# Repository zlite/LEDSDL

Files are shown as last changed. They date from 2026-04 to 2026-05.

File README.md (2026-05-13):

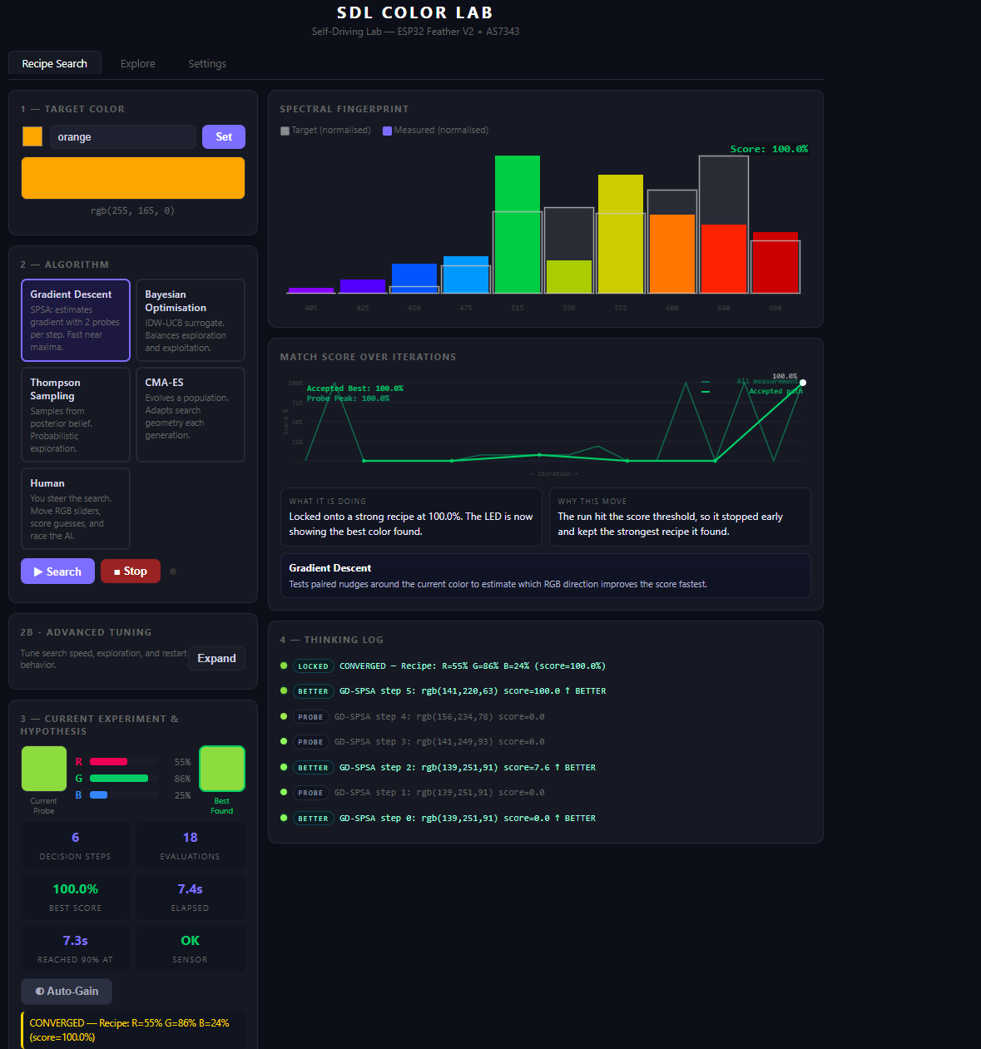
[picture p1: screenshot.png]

This is a minimal self-driving lab demonstration to "discover" color theory by doing an exploration/exploitation search of color space through driving a RGB LED and measuring it with a 14-channel color sensor. Users (often students) will learn about different SDL algorithms, such as Baysean Optimization and Gradient Descent, understanding why some are better at the task than others, and be able to try to beat the AI with "Human" mode. It all works via a web UI, but involves real-world data, where you can watch the experiments running in real time.

The whole thing can be made for $40, with no soldering required. It has an optional 400mah LiPo battery that the Feather can automatically recharge, making this a totally self-contained and portable SDL.

Instructions: Load code onto ESP32 with the Platormio extension in VSCode (change the port in the ini file to whatever your ESP32 shows up as). Codex or Claude Code extensions in VS Code will do this for you. Alternatively, you can just load the file on the ESP32 using the Arduino IDE.

3D print the two parts: [base](base.stl) and [cover](cover.stl). Everything is snap-together, no screws required.

If you haven't set your wifi details in the code, on startup after 30 seconds it will create its own Wifi access point called "SDL". Connect your phone or laptop to it and when prompted to login via a brower it will automatically take you to the app. Once in the app, in the setting tab you can search for your local Wifi network and enter in your password (if any) and press "Connect" (you only need to do this once; it will remember it next time). Once it's connected to your network, you should be able to open the UI in your web browser by just typing "sdl.local" in the URL bar. 

When plugged in via USB, the Feather will automatically charge the Lipo if you're using one.

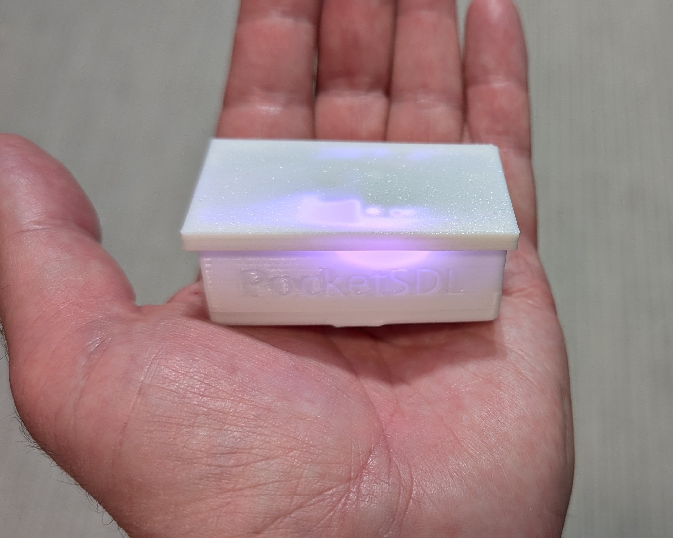
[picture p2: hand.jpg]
outside


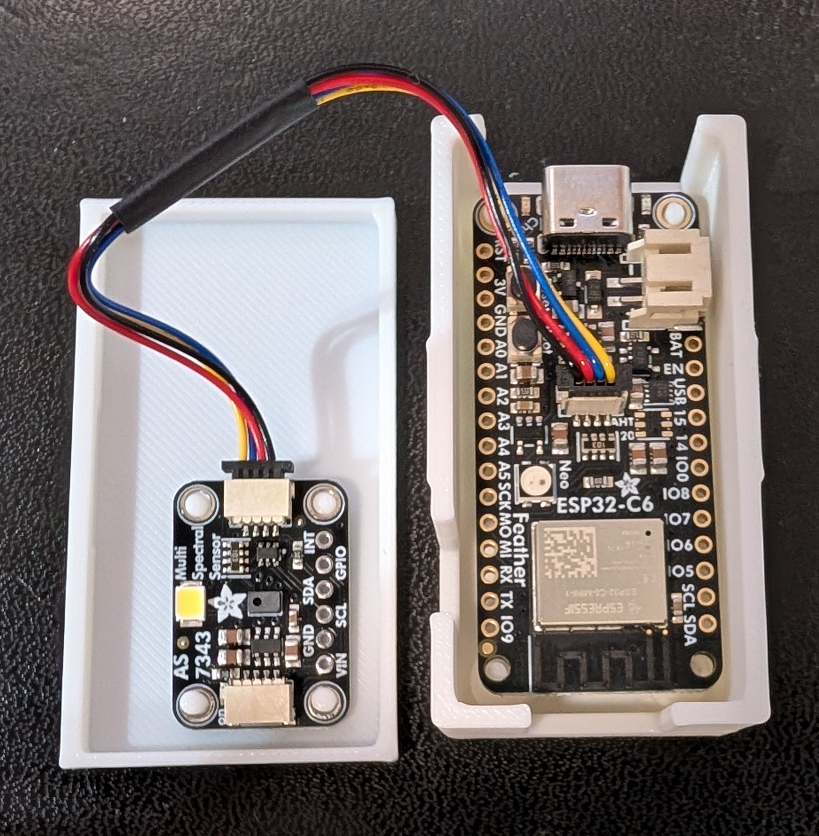
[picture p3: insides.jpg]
insides

----
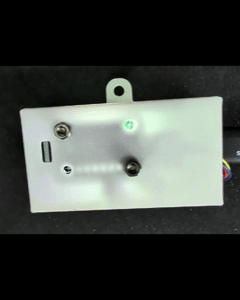
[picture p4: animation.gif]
flashing


**BOM**:
- [Adafruit Feather ESP32 C6](https://www.adafruit.com/product/5933) ($14.95)
- [Adafruit 10-channel color sensor](https://www.adafruit.com/product/4698) ($18.95)
- [Adafruit Stemma 4-pin cable, 50mm](https://www.adafruit.com/product/4399)  ($0.95, if out of stock, a longer cable can work, too)
- Optional [Adafruit 400mAh battery with short cable](https://www.adafruit.com/product/3898) ($6.95)

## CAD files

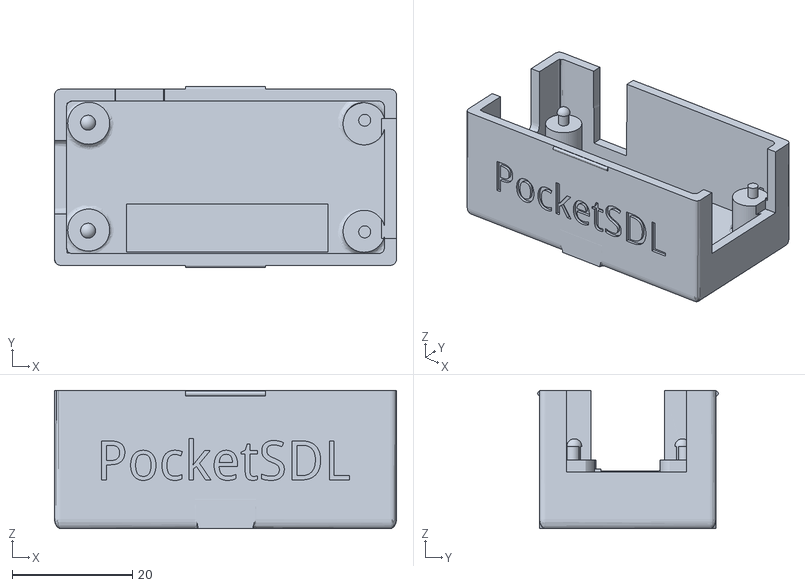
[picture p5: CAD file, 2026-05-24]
base.stl
57.0 x 30.1 x 23.0

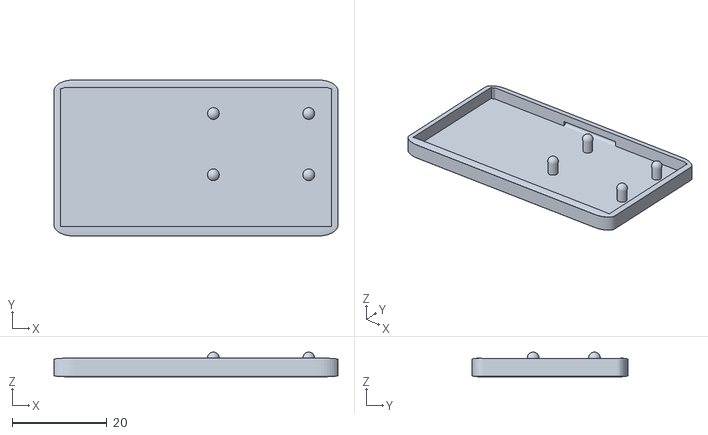
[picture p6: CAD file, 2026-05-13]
cover.stl
60.0 x 33.0 x 5.25

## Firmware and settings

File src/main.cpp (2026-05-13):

#include <Arduino.h>
#include <WiFi.h>
#include <DNSServer.h>
#include <AsyncTCP.h>
#include <ESPAsyncWebServer.h>
#include <ESPmDNS.h>
#include <Wire.h>
#include <math.h>
#include <Preferences.h>
#include <Adafruit_NeoPixel.h>

#if defined(SDL_SENSOR_AS7341) && defined(SDL_SENSOR_AS7343)
#error "Define only one of SDL_SENSOR_AS7341 or SDL_SENSOR_AS7343."
#endif

#if !defined(SDL_SENSOR_AS7341) && !defined(SDL_SENSOR_AS7343)
#define SDL_SENSOR_AS7343 1
#endif

#if defined(SDL_SENSOR_AS7341)
#include <Adafruit_AS7341.h>
#else
#include <Adafruit_AS7343.h>
#endif

// ── Hardware ──────────────────────────────────────────────────────────────────
#ifndef PIN_NEOPIXEL
#define PIN_NEOPIXEL 0
#endif

#if defined(PIN_NEOPIXEL_I2C_POWER)
#define SDL_NEOPIXEL_POWER PIN_NEOPIXEL_I2C_POWER
#elif defined(NEOPIXEL_I2C_POWER)
#define SDL_NEOPIXEL_POWER NEOPIXEL_I2C_POWER
#else
#define SDL_NEOPIXEL_POWER 2
#endif

#define NEOPIXEL_PIN   PIN_NEOPIXEL
#define NEOPIXEL_POWER SDL_NEOPIXEL_POWER
#define LED_BRIGHTNESS 200

#ifndef WIFI_SSID
#define WIFI_SSID "YOUR_WIFI_SSID"
#endif

#ifndef WIFI_PASS
#define WIFI_PASS "YOUR_WIFI_PASSWORD"
#endif

static const char WIFI_SSID_VALUE[] = WIFI_SSID;
static const char WIFI_PASS_VALUE[] = WIFI_PASS;
static const char AP_FALLBACK_SSID[] = "SDL";

#if defined(SDL_SENSOR_AS7341)
using SpectralSensor = Adafruit_AS7341;
using SensorGain = as7341_gain_t;
static const char SENSOR_DISPLAY_NAME[] = "AS7341";
static const char SENSOR_SUBTITLE[] = "Self-Driving Lab &mdash; ESP32 Feather V2 + AS7341";
static const int NUM_CH = 10;
static const int RAW_READ_CH = 12;
static const int N_SPEC = 8;
static const int SPEC_CH[] = {0,1,2,3,6,7,8,9};
static const float SPEC_WL[] = {415,445,480,515,555,590,630,680};
static const float W_R[NUM_CH]={0.00f,0.02f,0.08f,0.28f,0.00f,0.00f,0.55f,0.82f,1.00f,0.46f};
static const float W_G[NUM_CH]={0.03f,0.16f,0.55f,0.95f,0.00f,0.00f,0.78f,0.28f,0.03f,0.00f};
static const float W_B[NUM_CH]={0.52f,0.95f,0.78f,0.18f,0.00f,0.00f,0.01f,0.00f,0.00f,0.00f};
static const char SENSOR_JS_SPEC_IDX[] = "[0,1,2,3,6,7,8,9]";
static const char SENSOR_JS_SPEC_WL[] = "[415,445,480,515,555,590,630,680]";
static const char SENSOR_JS_SPEC_COL[] = "['#7f00ff','#2d5bff','#00a6ff','#00c96a','#c7d400','#ff9b00','#ff4d2b','#cc0017']";
static const char SENSOR_JS_CH_COL[] = "['#7f00ff','#2d5bff','#00a6ff','#00c96a','#bfbfbf','#777','#c7d400','#ff9b00','#ff4d2b','#cc0017']";
static const char SENSOR_JS_CH_LBL[] = "['415','445','480','515','Clr','NIR','555','590','630','680']";
static const char SENSOR_JS_W_R[] = "[0,0.02,0.08,0.28,0,0,0.55,0.82,1,0.46]";
static const char SENSOR_JS_W_G[] = "[0.03,0.16,0.55,0.95,0,0,0.78,0.28,0.03,0]";
static const char SENSOR_JS_W_B[] = "[0.52,0.95,0.78,0.18,0,0,0.01,0,0,0]";
static const char SENSOR_LOG_HEADER_HTML[] = "<th>415</th><th>445</th><th>480</th><th>515</th><th>555</th><th>590</th><th>630</th><th>680</th><th>Clr</th><th>NIR</th>";
static const char SENSOR_JS_LOG_IDX[] = "[0,1,2,3,6,7,8,9,4,5]";
#else
using SpectralSensor = Adafruit_AS7343;
using SensorGain = as7343_gain_t;
static const char SENSOR_DISPLAY_NAME[] = "AS7343";
static const char SENSOR_SUBTITLE[] = "Self-Driving Lab &mdash; ESP32 Feather V2 + AS7343";
static const int NUM_CH = 18;
static const int RAW_READ_CH = 18;
static const int N_SPEC = 10;
static const int SPEC_CH[] = {12,6,0,7,8,15,1,2,9,13};
static const float SPEC_WL[] = {405,425,450,475,515,550,555,600,640,690};
static const float W_R[NUM_CH]={0.00f,0.11f,0.68f,0.00f,0,0,0.00f,0.00f,0.00f,1.00f,0,0,0.00f,0.39f,0.02f,0.10f,0,0};
static const float W_G[NUM_CH]={0.08f,0.74f,0.12f,0.00f,0,0,0.01f,0.32f,0.93f,0.01f,0,0,0.00f,0.00f,0.00f,0.82f,0,0};
static const float W_B[NUM_CH]={0.98f,0.01f,0.00f,0.00f,0,0,0.49f,0.73f,0.06f,0.00f,0,0,0.14f,0.00f,0.00f,0.01f,0,0};
static const char SENSOR_JS_SPEC_IDX[] = "[12,6,0,7,8,15,1,2,9,13]";
static const char SENSOR_JS_SPEC_WL[] = "[405,425,450,475,515,550,555,600,640,690]";
static const char SENSOR_JS_SPEC_COL[] = "['#8800ff','#5500ff','#0055ff','#0099ff','#00cc44','#aacc00','#cccc00','#ff7700','#ff2200','#cc0000']";
static const char SENSOR_JS_CH_COL[] = "['#6600CC','#99CC00','#FF7700','#888','#bbb','#999','#4400FF','#0044FF','#00BB00','#FF2200','#bbb','#999','#9900FF','#CC0000','#880000','#CCEE00','#bbb','#999']";
static const char SENSOR_JS_CH_LBL[] = "['450','555','600','NIR','Cl','Cl','425','475','515','640','Cl','Cl','405','690','745','550','Cl','Cl']";
static const char SENSOR_JS_W_R[] = "[0,0.11,0.68,0,0,0,0,0,0,1,0,0,0,0.39,0.02,0.10,0,0]";
static const char SENSOR_JS_W_G[] = "[0.08,0.74,0.12,0,0,0,0.01,0.32,0.93,0.01,0,0,0,0,0,0.82,0,0]";
static const char SENSOR_JS_W_B[] = "[0.98,0.01,0,0,0,0,0.49,0.73,0.06,0,0,0,0.14,0,0,0.01,0,0]";
static const char SENSOR_LOG_HEADER_HTML[] = "<th>405</th><th>425</th><th>450</th><th>475</th><th>515</th><th>550</th><th>600</th><th>640</th><th>690</th><th>Clr</th>";
static const char SENSOR_JS_LOG_IDX[] = "[12,6,0,7,8,15,2,9,13,4]";
#endif

Adafruit_NeoPixel pixel(1, NEOPIXEL_PIN, NEO_GRB + NEO_KHZ800);
SpectralSensor    spectralSensor;
AsyncWebServer    server(80);
Preferences       prefs;
DNSServer         dnsServer;

static uint8_t ledR=0, ledG=0, ledB=0;
static bool    sensorOK=false;
static bool    apFallbackActive=false;
static String  wifiSSID;
static String  wifiPass;
static String  deviceHostName = "sdl";
static String  apSSID = AP_FALLBACK_SSID;

void setLED(uint8_t r, uint8_t g, uint8_t b){
  ledR=r; ledG=g; ledB=b;
  pixel.setPixelColor(0, pixel.Color(r,g,b)); pixel.show();
}

// ── Channel layout (18-ch mode) ───────────────────────────────────────────────
//  0:FZ/450  1:FY/555  2:FXL/600  3:NIR/855  4,5:CLR0
//  6:F2/425  7:F3/475  8:F4/515   9:F6/640   10,11:CLR1
// 12:F1/405 13:F7/690 14:F8/745  15:F5/550   16,17:CLR2
// ── Buffers ───────────────────────────────────────────────────────────────────
struct Reading { uint8_t r,g,b; uint16_t ch[NUM_CH]; };
static const int LOG_MAX=120; static Reading logBuf[LOG_MAX];
static int logHead=0, logCount=0;

struct Thought { uint8_t r,g,b; float score; bool improved; char msg[96]; };
static const int TH_MAX=50; static Thought thBuf[TH_MAX];
static int thHead=0, thCount=0;

static const int SCORE_MAX=200; static float scoreHist[SCORE_MAX];
static float acceptedScoreHist[SCORE_MAX];
static int scoreHead=0, scoreLen=0;
static int sensorReadFailures=0;

static String jsonEscape(const char* src);
static void setStateMessage(const char* msg);
static void stopExperiment(const char* msg, bool turnLedOff);
static bool hasCompileTimeWiFiCreds();
static bool loadStoredWiFiCreds();
static bool saveStoredWiFiCreds(const String& ssid, const String& pass);
static void loadNetworkSettings();
static bool saveNetworkSettings(const String& host, const String& ap);
static String normalizeHostName(String host);
static String normalizeApSsid(String ssid);
static String readSerialLine(bool echoInput = true);
static bool promptForWiFiCreds();
static void connectWiFi();
static void startFallbackAp();
static void startMdns();
static bool connectToNetwork(const String& ssid, const String& pass, uint32_t timeoutMs);
static void handleCaptivePortal(AsyncWebServerRequest* request);
static bool beginSpectralSensor();
static bool readSpectralChannels(uint16_t* readings);
static bool setSpectralGainIndex(int gainIdx);
static String buildHtml();
static bool parseJsonFloat(const String& body, const char* key, float& valueOut);
static String buildStatusJson();
static String buildScoresJson();
static String buildThoughtsJson();
static String buildLogJson();
static String buildSnapshotJson(bool includeLog);
static void queueHumanProbe(uint8_t r, uint8_t g, uint8_t b);
static String buildSettingsJson();
static void handleSettingsGet(AsyncWebServerRequest* request);
static void handleSettingsPost(AsyncWebServerRequest* request);
static void handleWifiScan(AsyncWebServerRequest* request);
static void handleWifiConnect(AsyncWebServerRequest* request);
static bool getRequestInt(AsyncWebServerRequest* request, const char* key, int& valueOut);
static bool getRequestFloat(AsyncWebServerRequest* request, const char* key, float& valueOut);
static bool getRequestString(AsyncWebServerRequest* request, const char* key, String& valueOut);
static bool getRequestRgb(AsyncWebServerRequest* request, uint8_t& r, uint8_t& g, uint8_t& b);

void pushScore(float s){
  int idx=scoreHead%SCORE_MAX;
  scoreHist[idx]=s;
  acceptedScoreHist[idx]=-1.0f;
  scoreHead++;
  if(scoreLen<SCORE_MAX)scoreLen++;
}
void pushAcceptedScore(float s){
  int idx=(scoreHead-1+SCORE_MAX)%SCORE_MAX;
  acceptedScoreHist[idx]=s;
}

void addThought(uint8_t r,uint8_t g,uint8_t b,float sc,bool imp,const char* msg){
  Thought& t=thBuf[thHead%TH_MAX]; t.r=r;t.g=g;t.b=b;t.score=sc;t.improved=imp;
  strncpy(t.msg,msg,95); t.msg[95]='\0'; thHead++; if(thCount<TH_MAX)thCount++;
  Serial.printf("[SDL] %s\n",msg);
}

// ── Spectral helpers ──────────────────────────────────────────────────────────
static float recTgtSpec[NUM_CH]={};   // raw target spectrum (sum-normalised in scoring)
static float ambSpec[NUM_CH]={};      // unused — kept for future reference
static uint8_t recTgtR=255, recTgtG=165, recTgtB=0;

static bool isSaturated(const uint16_t* buf){
  for(int i=0;i<N_SPEC;i++) if(buf[SPEC_CH[i]]>60000) return true;
  return false;
}

// Score: 1 - L2 distance between sum-normalised spectra (probability distributions).
// Ambient (dark frame) is subtracted before normalisation so room light doesn't corrupt shape.
// sqrtf(l2) ranges 0 (identical shape) to sqrt(2) (orthogonal), mapped to 0–100%.
float computeScore(const uint16_t* meas){
  if(isSaturated(meas)) return 0.0f;
  float m[N_SPEC], t[N_SPEC];
  float msum=0, tsum=0;
  for(int i=0;i<N_SPEC;i++){
    int ci=SPEC_CH[i];
    m[i]=max(0.0f,(float)meas[ci]-ambSpec[ci]);
    t[i]=recTgtSpec[ci];
    msum+=m[i]; tsum+=t[i];
  }
  if(msum<1.0f||tsum<1.0f) return 0.0f;
  // Luminance penalty: a dim colour that has the right hue shape still scores low.
  // sqrtf keeps it gentle — 50% brightness → 71% penalty, 25% → 50%.
  float lumPenalty = msum < tsum ? sqrtf(msum/tsum) : 1.0f;
  float l2=0;
  for(int i=0;i<N_SPEC;i++){
    float diff=m[i]/msum - t[i]/tsum;
    l2+=diff*diff;
  }
  // Denominator 0.45 calibrated so a random colour averages ~50%; a true match scores ~90%+.
  return max(0.0f,(1.0f - sqrtf(l2)/0.45f)*100.0f) * lumPenalty;
}

void genTargetSpectrum(uint8_t r,uint8_t g,uint8_t b){
  float rf=r/255.0f,gf=g/255.0f,bf=b/255.0f;
  for(int i=0;i<NUM_CH;i++) recTgtSpec[i]=rf*W_R[i]+gf*W_G[i]+bf*W_B[i];
}

// Gaussian random (Box-Muller)
float gaussRand(){
  float u1=max(1e-6f,(float)random(1,1000000)/1000000.0f);
  float u2=(float)random(0,1000000)/1000000.0f;
  return sqrtf(-2.0f*logf(u1))*cosf(2.0f*M_PI*u2);
}

// ── Algorithm state ───────────────────────────────────────────────────────────
enum Alg { ALG_NONE=0, ALG_SPSA, ALG_BAYES, ALG_THOMPSON, ALG_CMAES, ALG_HUMAN };
static Alg   alg=ALG_NONE;
static bool  running=false, settling=false;
static uint32_t nextMs=0;
static uint32_t settleMs=200, pauseMs=30;

static float spsaInitH=40.0f, spsaInitA=60.0f;
static int   spsaRestartPatience=40;
static float boKappaInit=3.0f;
static int   boCandidateCount=80;
static float tsBwInit=0.25f;
static int   tsCandidateCount=80;
static float cmaSigmaInit=32.0f;
static int   cmaMuActive=3;
static const int HUMAN_MAX_TRIES=10;

static uint8_t  bestR=128,bestG=128,bestB=128;
static float    bestScore=-1.0f;
static int      totalIter=0;
static int      evalCount=0;
static uint32_t runStartMs=0;
static int32_t  hit90Ms=-1;
static bool     converged=false;
static int      calibPhase=0;  // 0=running, 1=dark reading, 2=target reading
static float    lastScore=0.0f;
static char     stateMsg[100]="Set a target color and press Search.";
static bool     humanProbePending=false;
static bool     humanAwaitingProbe=false;
static uint8_t  humanProbeR=128, humanProbeG=128, humanProbeB=128;

static String jsonEscape(const char* src){
  String out;
  if(!src) return out;
  while(*src){
    char c=*src++;
    switch(c){
      case '\\': out+="\\\\"; break;
      case '"':  out+="\\\""; break;
      case '\n': out+="\\n"; break;
      case '\r': out+="\\r"; break;
      case '\t': out+="\\t"; break;
      default:
        if((uint8_t)c >= 0x20) out += c;
        break;
    }
  }
  return out;
}

static void setStateMessage(const char* msg){
  if(!msg){
    stateMsg[0]='\0';
    return;
  }
  strncpy(stateMsg,msg,sizeof(stateMsg)-1);
  stateMsg[sizeof(stateMsg)-1]='\0';
}

static void stopExperiment(const char* msg, bool turnLedOff){
  running=false;
  settling=false;
  calibPhase=0;
  humanProbePending=false;
  humanAwaitingProbe=false;
  if(msg) setStateMessage(msg);
  if(turnLedOff) setLED(0,0,0);
}

static bool hasCompileTimeWiFiCreds(){
  return strcmp(WIFI_SSID_VALUE,"YOUR_WIFI_SSID")!=0;
}

static bool loadStoredWiFiCreds(){
  if(!prefs.begin("wifi", true)) return false;
  wifiSSID = prefs.getString("ssid", "");
  wifiPass = prefs.getString("pass", "");
  prefs.end();
  return wifiSSID.length() > 0;
}

static bool saveStoredWiFiCreds(const String& ssid, const String& pass){
  if(!prefs.begin("wifi", false)) return false;
  bool ok = prefs.putString("ssid", ssid) > 0;
  prefs.putString("pass", pass);
  prefs.end();
  return ok;
}

static String normalizeHostName(String host){
  host.trim();
  host.toLowerCase();
  if(host.endsWith(".local")) host = host.substring(0, host.length() - 6);
  String out;
  for(size_t i=0;i<host.length() && out.length()<32;i++){
    char c=host[i];
    bool ok=(c>='a'&&c<='z')||(c>='0'&&c<='9')||c=='-';
    if(ok) out += c;
  }
  while(out.startsWith("-")) out.remove(0,1);
  while(out.endsWith("-")) out.remove(out.length()-1);
  return out.length() ? out : "sdl";
}

static String normalizeApSsid(String ssid){
  ssid.trim();
  if(!ssid.length()) ssid = "SDL";
  if(ssid.length() > 31) ssid = ssid.substring(0, 31);
  return ssid;
}

static void loadNetworkSettings(){
  if(!prefs.begin("net", true)) return;
  deviceHostName = normalizeHostName(prefs.getString("host", "sdl"));
  apSSID = normalizeApSsid(prefs.getString("ap", AP_FALLBACK_SSID));
  prefs.end();
}

static bool saveNetworkSettings(const String& host, const String& ap){
  String cleanHost = normalizeHostName(host);
  String cleanAp = normalizeApSsid(ap);
  if(!prefs.begin("net", false)) return false;
  bool ok = prefs.putString("host", cleanHost) > 0;
  ok = prefs.putString("ap", cleanAp) > 0 && ok;
  prefs.end();
  deviceHostName = cleanHost;
  apSSID = cleanAp;
  return ok;
}

static String readSerialLine(bool echoInput){
  String line;
  while(true){
    while(!Serial.available()) delay(10);
    char c = (char)Serial.read();
    if(c == '\r') continue;
    if(c == '\n'){
      if(echoInput) Serial.println();
      break;
    }
    if(c == '\b' || c == 127){
      if(line.length() > 0){
        line.remove(line.length() - 1);
        if(echoInput) Serial.print("\b \b");
      }
      continue;
    }
    if((uint8_t)c < 0x20) continue;
    line += c;
    if(echoInput) Serial.print(c);
  }
  return line;
}

static bool promptForWiFiCreds(){
  Serial.println();
  Serial.println("WiFi credentials not found.");
  Serial.println("Enter them in the serial monitor and press Enter.");
  while(true){
    Serial.print("SSID: ");
    wifiSSID = readSerialLine();
    if(wifiSSID.length() > 0) break;
    Serial.println("SSID cannot be empty.");
  }
  Serial.print("Password (leave blank for open network): ");
  wifiPass = readSerialLine();
  if(!saveStoredWiFiCreds(wifiSSID, wifiPass)){
    Serial.println("WARN: failed to save WiFi credentials to NVS.");
  } else {
    Serial.println("Saved WiFi credentials.");
  }
  return true;
}

static void connectWiFi(){
  apFallbackActive=false;
  loadNetworkSettings();
  if(hasCompileTimeWiFiCreds()){
    wifiSSID = WIFI_SSID_VALUE;
    wifiPass = WIFI_PASS_VALUE;
  } else if(!loadStoredWiFiCreds()){
    Serial.println("WiFi credentials not found. Starting fallback AP for setup.");
    startFallbackAp();
    return;
  }

  if(wifiSSID.length() == 0){
    Serial.println("WiFi disabled: no credentials available. Starting fallback AP.");
    startFallbackAp();
    return;
  }

  Serial.print("Connecting to ");
  Serial.print(wifiSSID);
  Serial.print(" ");
  setLED(0,0,60);
  if(connectToNetwork(wifiSSID, wifiPass, 30000)){
    startMdns();
    setLED(0,60,0);delay(1200);setLED(0,0,0);
  } else {
    Serial.println("\nWiFi failed after 30 seconds. Starting fallback AP.");
    WiFi.disconnect(true, true);
    startFallbackAp();
  }
}

static void startFallbackAp(){
  loadNetworkSettings();
  WiFi.mode(WIFI_AP_STA);
  if(WiFi.softAP(apSSID.c_str())){
    IPAddress apIp = WiFi.softAPIP();
    String apUrl = "http://" + apIp.toString();
    apFallbackActive=true;
    dnsServer.start(53, "*", apIp);
    Serial.println("Open WiFi AP started.");
    Serial.println("SSID: " + apSSID);
    Serial.println("Open: " + apUrl);
    Serial.println("Captive portal DNS started.");
    setStateMessage(("AP fallback active: join " + apSSID + " at " + apUrl).c_str());
    setLED(60,30,0);delay(1200);setLED(0,0,0);
  } else {
    apFallbackActive=false;
    Serial.println("ERROR: failed to start fallback AP.");
    setStateMessage("WiFi failed and AP fallback could not start.");
    setLED(60,0,0);delay(2000);setLED(0,0,0);
  }
}

static void startMdns(){
  MDNS.end();
  if(MDNS.begin(deviceHostName.c_str())){
    MDNS.addService("http", "tcp", 80);
    Serial.println("\nOpen: http://" + deviceHostName + ".local or http://" + WiFi.localIP().toString());
    setStateMessage(("WiFi connected at http://" + deviceHostName + ".local").c_str());
  } else {
    Serial.println("\nOpen: http://" + WiFi.localIP().toString());
    Serial.println("WARN: mDNS failed to start; use the IP address instead.");
    setStateMessage("WiFi connected (mDNS unavailable).");
  }
}
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
void loop(){
  if(apFallbackActive) dnsServer.processNextRequest();
  if(!running) return;
  if(!sensorOK){
    stopExperiment("Sensor unavailable. Search cannot run.", true);
    return;
  }
  uint32_t now=millis(); if(now<nextMs) return;
  if(!settling){
    if(calibPhase!=0){ settling=true; nextMs=now+settleMs; return; } // wait for calibration
    switch(alg){
      case ALG_SPSA:     stepSPSA();    break;
      case ALG_BAYES:    stepBO();      break;
      case ALG_THOMPSON: stepTS();      break;
      case ALG_CMAES:    stepCMA();     break;
      case ALG_HUMAN:
        if(!humanProbePending) return;
        setLED(humanProbeR,humanProbeG,humanProbeB);
        humanProbePending=false;
        humanAwaitingProbe=true;
        break;
      default: break;
    }
    settling=true; nextMs=now+settleMs;
  } else {
    uint16_t buf[NUM_CH]={};
    if(readSpectralChannels(buf)){
      sensorReadFailures=0;
      if(calibPhase==1){
        // Dark frame: LED off — store ambient spectrum then light the target color.
        for(int i=0;i<NUM_CH;i++) ambSpec[i]=(float)buf[i];
        calibPhase=2;
        setLED(recTgtR,recTgtG,recTgtB);
        char msg[100];
        snprintf(msg,sizeof(msg),"Calibrating: reading target rgb(%d,%d,%d)...",recTgtR,recTgtG,recTgtB);
        setStateMessage(msg);
        settling=true; nextMs=now+settleMs;
        return;
      }
      if(calibPhase==2){
        // Target frame: subtract ambient so only LED contribution is stored.
        if(isSaturated(buf)){
          if(currentGainIdx>0){
            currentGainIdx--;
            setSpectralGainIndex(currentGainIdx);
            Serial.printf("Calib saturated, reducing gain to idx=%d\n",currentGainIdx);
            setStateMessage("Calibration saturated, reducing sensor gain...");
            settling=true; nextMs=now+settleMs;
            return;
          }
          stopExperiment("Calibration saturated at minimum gain. Lower LED brightness or move the sensor back.", true);
          return;
        }
        for(int i=0;i<NUM_CH;i++) recTgtSpec[i]=max(0.0f,(float)buf[i]-ambSpec[i]);
        calibPhase=0;
        setStateMessage("Calibrated. Searching from random start...");
        switch(alg){
          case ALG_SPSA:     initSPSA();    break;
          case ALG_BAYES:    initBO();      break;
          case ALG_THOMPSON: initTS();      break;
          case ALG_CMAES:    initCMA();     break;
          case ALG_HUMAN:
            humanAwaitingProbe=false;
            humanProbePending=false;
            setLED(0,0,0);
            setStateMessage("Human mode ready. Adjust a color and press Score Guess.");
            break;
          default: break;
        }
        if(alg==ALG_HUMAN){
          settling=false; nextMs=now;
        } else {
          settling=false; nextMs=now+pauseMs;
        }
        return;
      }
      int idx=logHead%LOG_MAX;
      Reading& rd=logBuf[idx]; rd.r=ledR;rd.g=ledG;rd.b=ledB;
      memcpy(rd.ch,buf,sizeof(rd.ch)); logHead++; if(logCount<LOG_MAX)logCount++;
      evalCount++;
      float sc=computeScore(buf);
      lastScore=sc;
      switch(alg){
        case ALG_SPSA:     afterSPSA(rd,sc);    break;
        case ALG_BAYES:    afterBO(rd,sc);      break;
        case ALG_THOMPSON: afterTS(rd,sc);      break;
        case ALG_CMAES:    afterCMA(rd,sc);     break;
        case ALG_HUMAN:    afterHuman(rd,sc);   break;
        default: break;
      }
    } else {
      sensorReadFailures++;
      Serial.printf("WARN: readAllChannels failed (%d)\n",sensorReadFailures);
      if(sensorReadFailures >= 5){
        stopExperiment("Repeated sensor read failures. Check wiring/power and recalibrate.", true);
        return;
      }
    }
    if(alg==ALG_HUMAN){
      settling=false; nextMs=now;
    } else {
      settling=false; nextMs=now+pauseMs;
    }
  }
}

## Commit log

2026-04-16 Initialize README with project overview and BOM
    Added project description and BOM for self-driving lab.
2026-04-18 Add BOM section and image to README
2026-04-21 Added option to switch to AP mode and use 10-channel sensor
2026-05-07 Updated to be press fit (no bolts required)
    [cover.stl]
2026-05-13 Now better fitting and includes space for battery
    [base.stl, cover.stl]
2026-05-13 Revise battery and WiFi setup instructions
    Updated battery specifications and WiFi connection instructions in README.
2026-05-13 Revise README for clarity and additional instructions
    Updated project description for clarity and added instructions for 3D printing and WiFi setup.
2026-05-13 Fixed LED, which is on different pins with the C6
    [main.cpp]
2026-05-13 Enhance README with project details and instructions
    Expanded the project description to include details about the 14-channel color sensor and the learning experience for users. Clarified instructions for loading code onto the ESP32 and 3D printing par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
2026-05-13 Fix Adafruit Feather ESP32 C6 product link
    Updated the product link for Adafruit Feather ESP32 C6.
2026-05-13 Revise README for clarity and add component prices
    Updated the project description for clarity and added pricing information for components in the BOM.
2026-05-13 Clarify 3D printing instructions in README
    Updated instructions for 3D printing parts and clarified file references.
2026-05-13 Fix formatting for 3D print part links in README
    Corrected formatting for 3D printing instructions in README.
2026-05-13 Format BOM section in README.md
2026-05-13 Minor tweaks
    [base.stl, cover.stl]
2026-05-24 slight tweaks to snap better
    [base.stl]
